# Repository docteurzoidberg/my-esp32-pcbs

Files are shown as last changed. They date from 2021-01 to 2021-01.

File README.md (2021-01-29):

# my-esp32-pcbs
This repository regroups all of my custom esp32 pcbs. These pcbs are meant to be generic and usable in a large panel of projects.
## espBreakout

Breakout board for 38 pins esp32.
- Configurable power distribution (3.3V/5V)
- 6 phoenix-style connectors for i/o  
Last revision: v1.1

## espBreakout-adc-module

I2C extension for the espBreakout
- 2x 4 channels adc (ax)
- 8 phoenix-style connectors for i/o
Last revision: WIP

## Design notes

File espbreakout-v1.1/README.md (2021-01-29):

# espbreakout

Breakout board for 38 pins esp32.

## ESP32 versions

- I worked with az-delivery esp32 boards.  
**links**

## Pictures

//todo

## Features

- 6 Phoenix connectors (3 pins, 3.81mm pitch) to use with prewired GPIOS or custom ones
- choosable power (3 or 5V) for each Phoenix connector
- JST-PH 2mm style 5 pins connector for I2C (providing both 3.3 and 5V power)
- JST-PH 2mm style 5 pins connector for SERIAL
- 3 SMD LEDs to use with prewired configuration or custom GPIOs
- global board GND among all connectors

## Power distribution

- Each phoenix connector got a (+) pin that can be either tied to 3v or 5v rail. The desired voltage can be connected to the phoenix connector through a solder jumper.

- Each phoenix connector got a GND pin linked to global board GND.

## LEDs

3 SMD LEDs placeholders are included, you are free to use them.
Each LED have a solder jumper, and a resistor placeholder next to it.

- LED1 can be tied to 5V rail through solder jumper.

- LED2 can be tied to GPIO32 through solder jumper.

- LED3 can be tied to GPIO4 through solder jumper.

Please, beware of choosing the right resistor for either 5V or 3V power GPIOs, depending on your solder jumper setup!

## Data

- J1 data pin can be tied (actually nothing. needs to be fixed...) when solder jumper closed

- J2 data pin can be tied to GPIO25 through solder jumper.

- J3 data pin can be tied to GPIO5 through solder jumper.

- J4 data pin can be tied to GPIO26 through solder jumper.

- J5 data pin can be tied to GPIO33 through solder jumper.

- J6 data pin can be tied to GPIO32* through solder jumper.

*J6 data pin and LED2 can be tied on the same pin (GPIO32). This is expected behavior.  
I'm using this output for a relay and the led reflects its status.

When the solder jumper of a data pin is not connected, you are free to tied it to any pin on the esp. A simple wire to the pad next to the ESP's pin does the job.

//todo pictures of custom pin mapping

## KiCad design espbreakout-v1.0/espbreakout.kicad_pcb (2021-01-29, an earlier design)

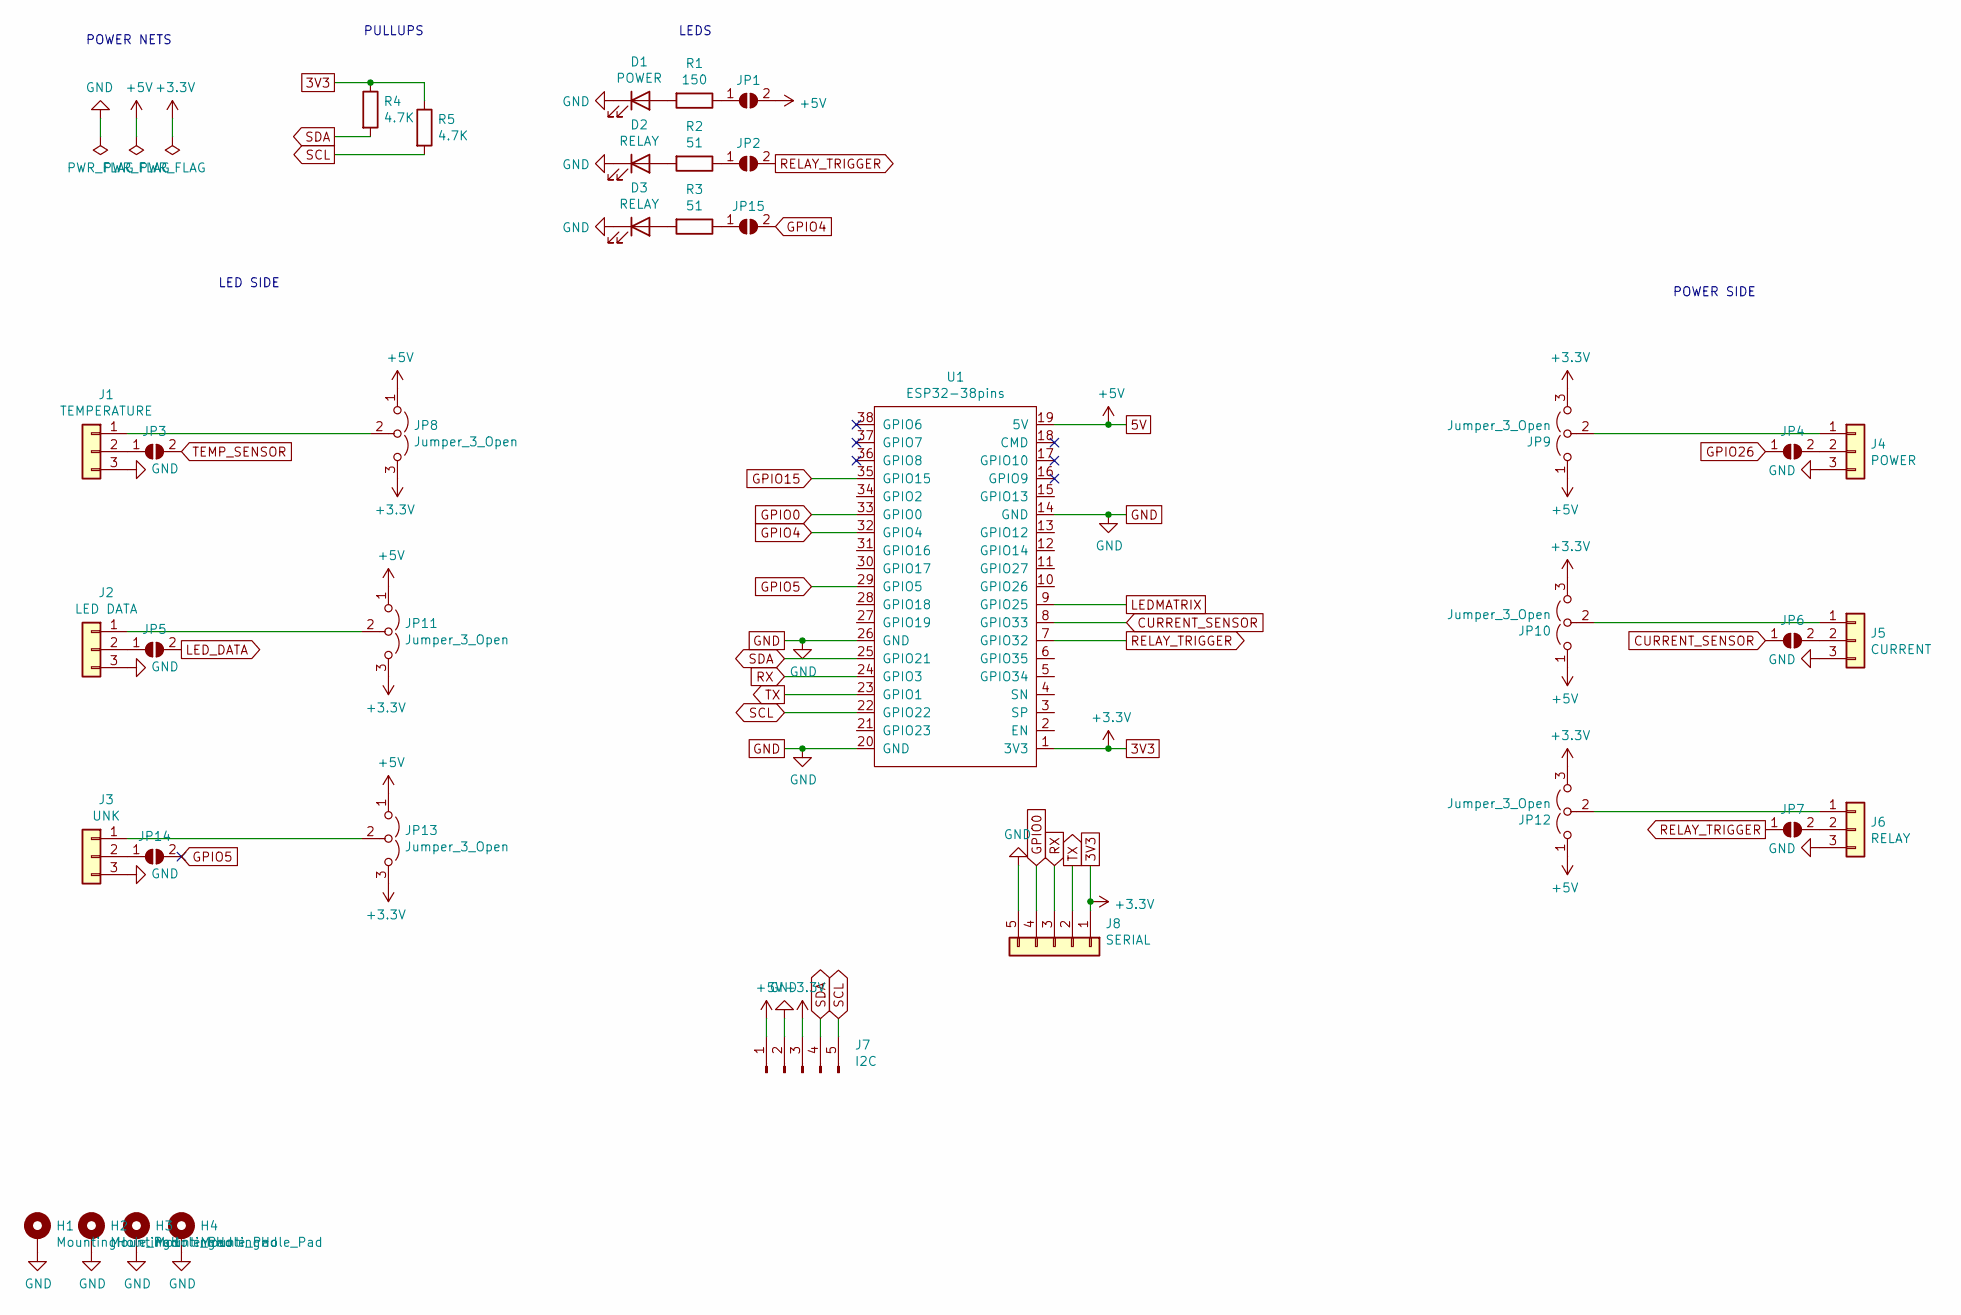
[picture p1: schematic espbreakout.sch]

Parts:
D1: POWER; LED_1206_3216Metric_Pad1.42x1.75mm_HandSolder
D2, D3: RELAY; LED_1206_3216Metric_Pad1.42x1.75mm_HandSolder
H1, H2, H3, H4: MountingHole_Pad; MountingHole_3.2mm_M3_Pad_Via
J1: TEMPERATURE; PhoenixContact_MCV-G_03x3.81mm_Vertical
J2: LED DATA; PhoenixContact_MCV-G_03x3.81mm_Vertical
J3: UNK; PhoenixContact_MCV-G_03x3.81mm_Vertical
J4: POWER; PhoenixContact_MCV-G_03x3.81mm_Vertical
J5: CURRENT; PhoenixContact_MCV-G_03x3.81mm_Vertical
J6: RELAY; PhoenixContact_MCV-G_03x3.81mm_Vertical
J7: I2C; JST_PH_S5B-PH-K_05x2.00mm_Angled
J8: SERIAL; Pin_Header_Straight_1x05_Pitch2.54mm
JP1, JP2, JP15: PLJP; SolderJumper-2_P1.3mm_Open_RoundedPad1.0x1.5mm
JP3, JP5, JP14: SolderJumper_2_Open; SolderJumper-2_P1.3mm_Open_TrianglePad1.0x1.5mm
JP4, JP6, JP7: D; SolderJumper-2_P1.3mm_Open_TrianglePad1.0x1.5mm
JP8, JP9, JP10, JP11, JP12, JP13: Jumper_3_Open; SolderJumper-3_P1.3mm_Open_Pad1.0x1.5mm
R1: 150; R_0805_HandSoldering
R2, R3: 51; R_0805_HandSoldering
R4, R5: 4.7K; R_0805_HandSoldering
U1: ESP32-38pins; esp32 38pin azdelivery

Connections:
3V3: J7.3, J8.1, JP8.3 (B), JP9.3 (B), JP10.3 (B), JP11.3 (B), JP12.3 (B), JP13.3 (B), R4.1, R5.1, U1.1 (3V3)
5V: J7.1, JP1.2 (B), JP8.1 (A), JP9.1 (A), JP10.1 (A), JP11.1 (A), JP12.1 (A), JP13.1 (A), U1.19 (5V)
CURRENT_SENSOR: JP6.1 (A), U1.8 (GPIO33)
GND: D1.1 (K), D2.1 (K), D3.1 (K), H1.1, H2.1, H3.1, H4.1, J1.3, J2.3, J3.3, J4.3, J5.3, J6.3, J7.2, J8.5, U1.14 (GND), U1.20 (GND), U1.26 (GND)
GPIO0: J8.4, U1.33 (GPIO0)
GPIO4: JP15.2 (B), U1.32 (GPIO4)
GPIO5: JP14.2 (B), U1.29 (GPIO5)
GPIO15: U1.35 (GPIO15)
GPIO26: JP4.1 (A)
LEDMATRIX: U1.9 (GPIO25)
LED_DATA: JP5.2 (B)
unnamed: D1.2 (A), R1.2
unnamed: D2.2 (A), R2.2
unnamed: D3.2 (A), R3.2
unnamed: J1.1, JP8.2 (C)
unnamed: J1.2, JP3.1 (A)
unnamed: J2.1, JP11.2 (C)
unnamed: J2.2, JP5.1 (A)
unnamed: J3.1, JP13.2 (C)
unnamed: J3.2, JP14.1 (A)
unnamed: J4.1, JP9.2 (C)
unnamed: J4.2, JP4.2 (B)
unnamed: J5.1, JP10.2 (C)
unnamed: J5.2, JP6.2 (B)
unnamed: J6.1, JP12.2 (C)
unnamed: J6.2, JP7.2 (B)
unnamed: JP1.1 (A), R1.1
unnamed: JP2.1 (A), R2.1
unnamed: JP15.1 (A), R3.1
RELAY_TRIGGER: JP2.2 (B), JP7.1 (A), U1.7 (GPIO32)
RX: J8.3, U1.24 (GPIO3)
SCL: J7.5, R5.2, U1.22 (GPIO22)
SDA: J7.4, R4.2, U1.25 (GPIO21)
TEMP_SENSOR: JP3.2 (B)
TX: J8.2, U1.23 (GPIO1)

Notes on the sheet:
LED SIDE
POWER SIDE
PULLUPS
POWER NETS
LEDS

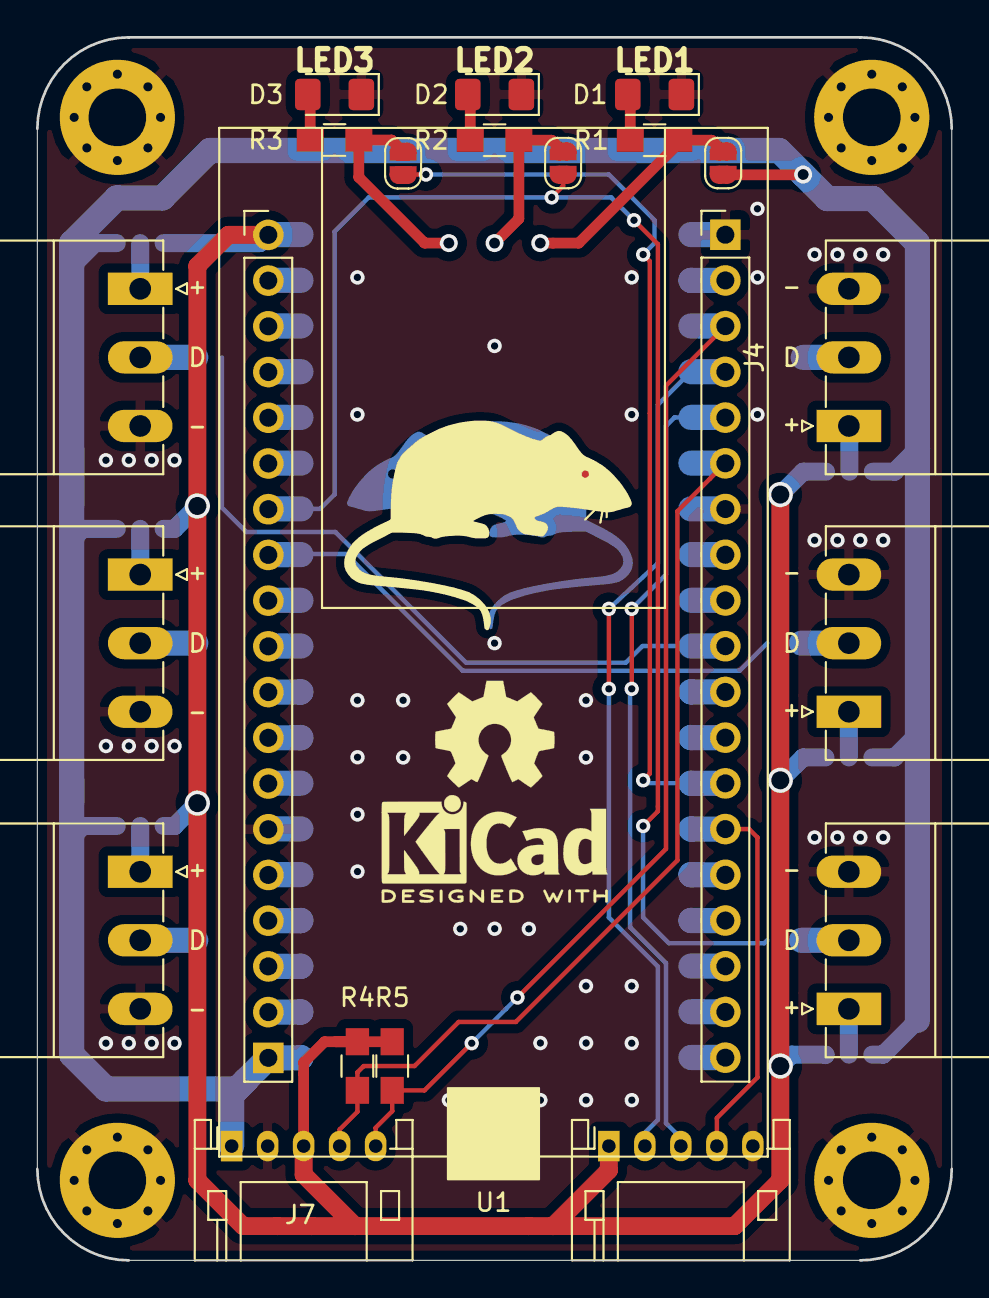
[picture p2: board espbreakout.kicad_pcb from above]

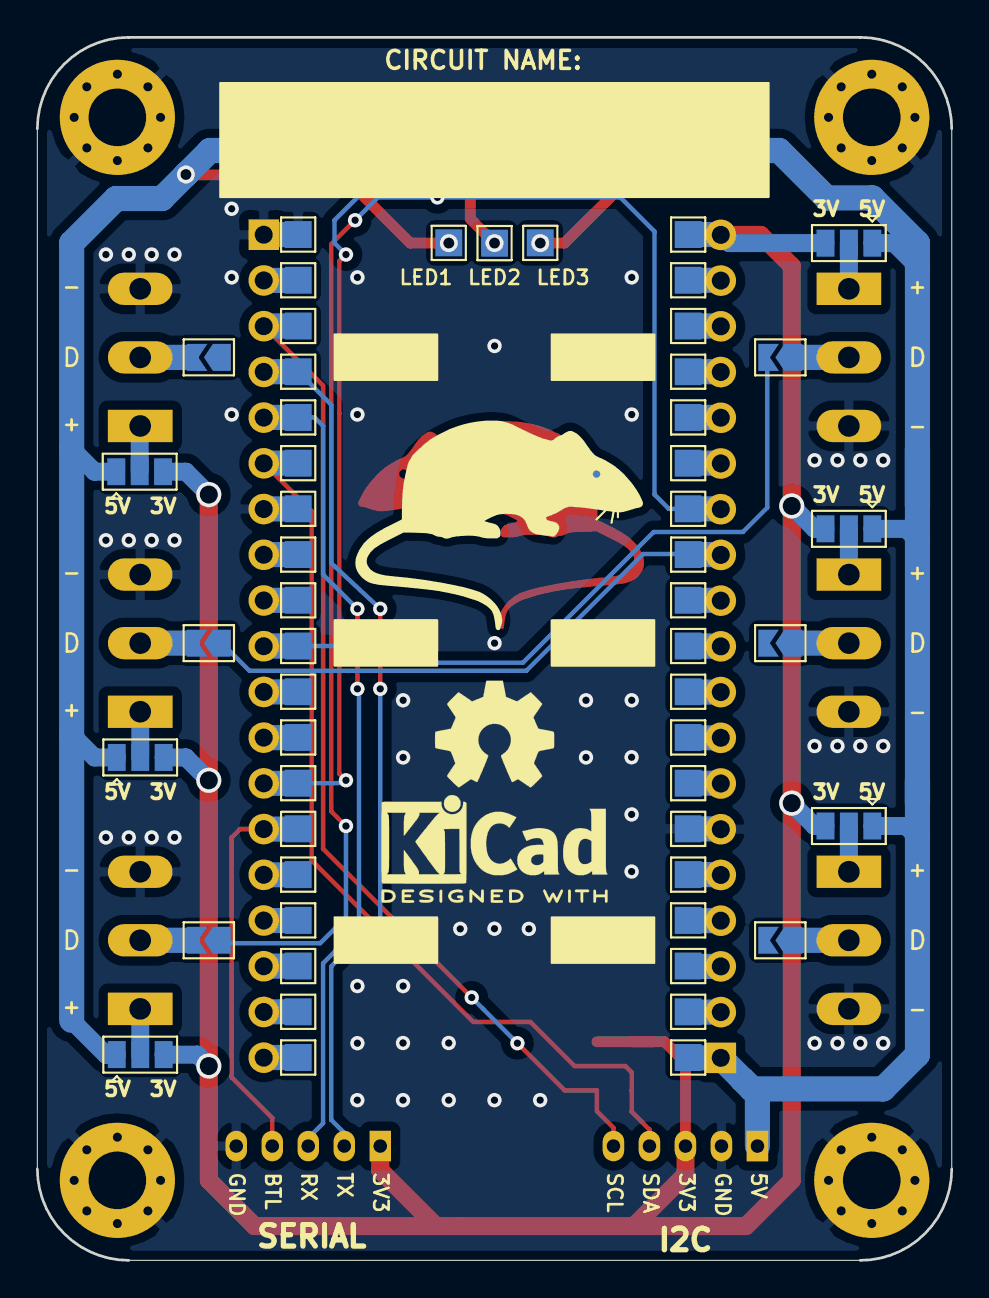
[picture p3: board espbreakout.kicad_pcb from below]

Board: 2 copper layers, 50.8 x 67.9 mm, 36 parts (12 on the bottom side), 30 nets.

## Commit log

2021-01-23 add v.10 board
2021-01-23 easpbreakout adc module wip
    [espbreakout-adc-module.kicad_pcb, espbreakout-adc-module.sch]
2021-01-29 espbreakout v1.0 for eurotrash and jesserockz
    [espbreakout-B_Cu.gbr, espbreakout-B_Mask.gbr, espbreakout-B_Paste.gbr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]
2021-01-29 espbreakout v1.0 move
    [espbreakout-B_Cu.gbr, espbreakout-B_Mask.gbr, espbreakout-B_Paste.gbr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]
